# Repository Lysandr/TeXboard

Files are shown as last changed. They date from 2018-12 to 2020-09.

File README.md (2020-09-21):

# TeXboard
I designed a mechanical keyboard from scratch for the scientists, mathematicians, and control theorists of the world. It has LaTeX bindings for math and greek.

This also works as generic keyboard matrix interpretation code. Writtenin C-arduino for the teensy 3.1/2

12/1/2018 havent quite worked out some bugs in Latex, and functions. Excuse: I have spent maybe 2 hours on software.
2/14/2018 adding support for MkII.

Todo:
FN/GRK/LTX functions still need to be implemented (imlazy)
dual keys tend to have an odd glitch, needs to be investigated
MkIII hardware --> switch over to STM32 with QMK firmware... also put extension keys on the left, gives more mouse room. Create parametric case design, which prints perfectly and makes lasercut piece easier to deal with.

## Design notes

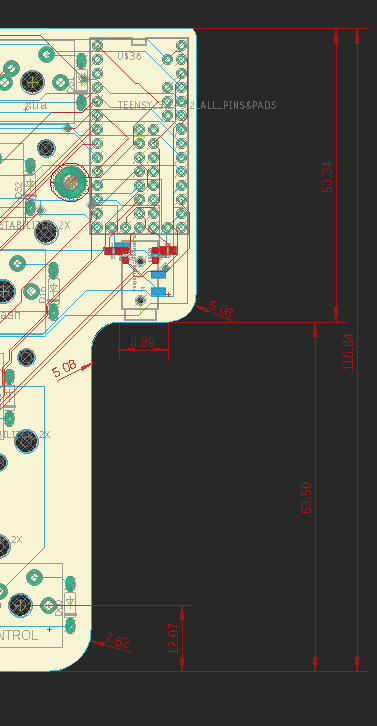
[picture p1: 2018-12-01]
dims_texbrd.PNG

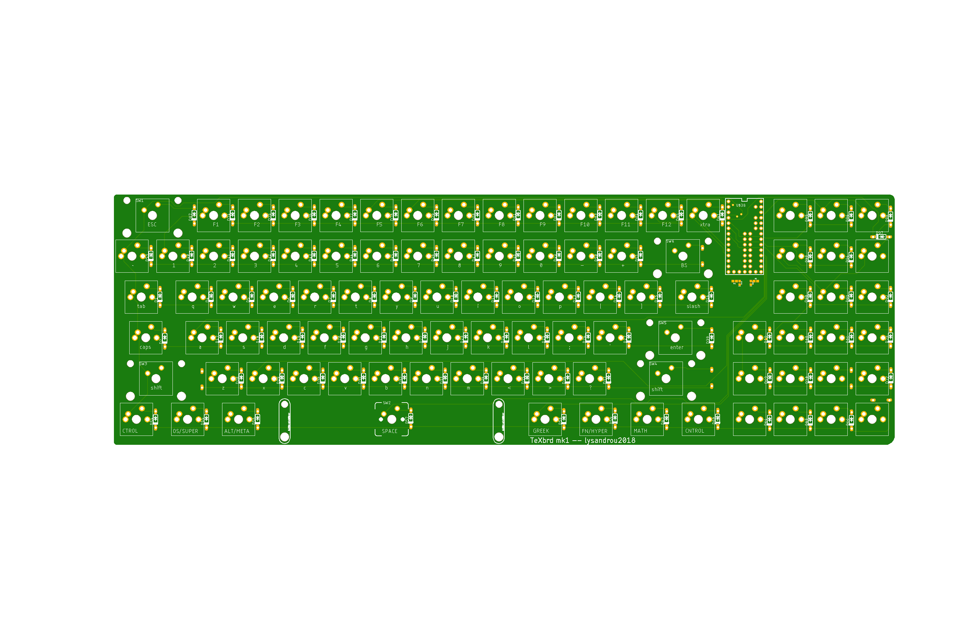
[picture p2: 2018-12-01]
texboard_hw_mk3/texboard.png

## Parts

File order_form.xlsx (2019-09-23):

Item | Quantity | Price Per
Diodes | 98 | 7
Switches: Kailh Red | 98
PCB | 1 | 5
Case | 1 | 5

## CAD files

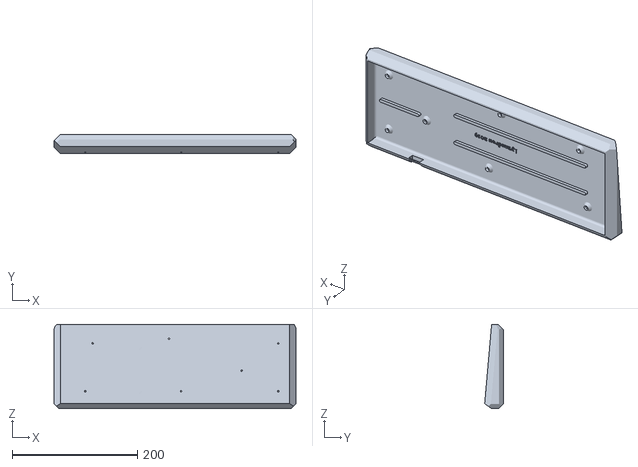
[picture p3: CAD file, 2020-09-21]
texboard.stl
385.7 x 29.7 x 134.2

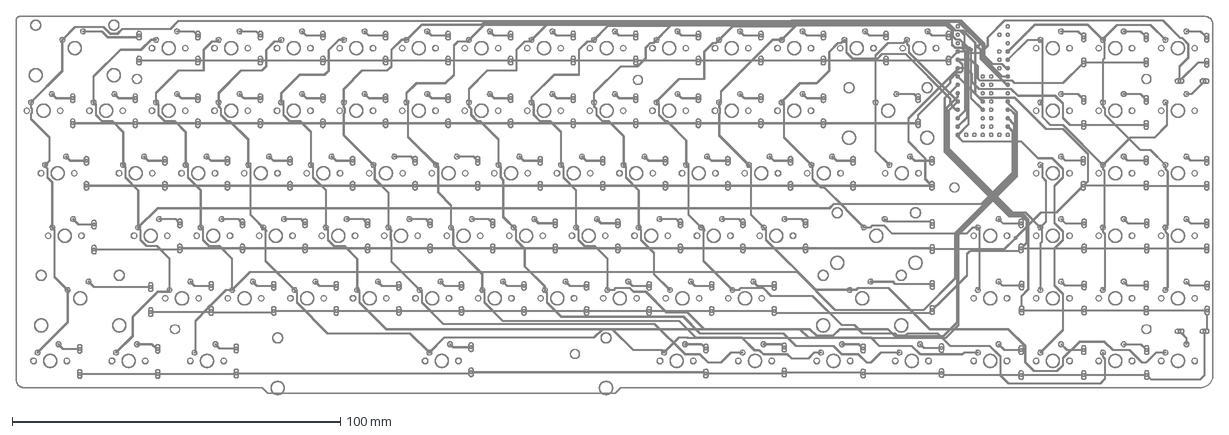
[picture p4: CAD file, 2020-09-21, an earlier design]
texboard_hw_mk2/texboard.dxf
364.5 x 115.1 mm

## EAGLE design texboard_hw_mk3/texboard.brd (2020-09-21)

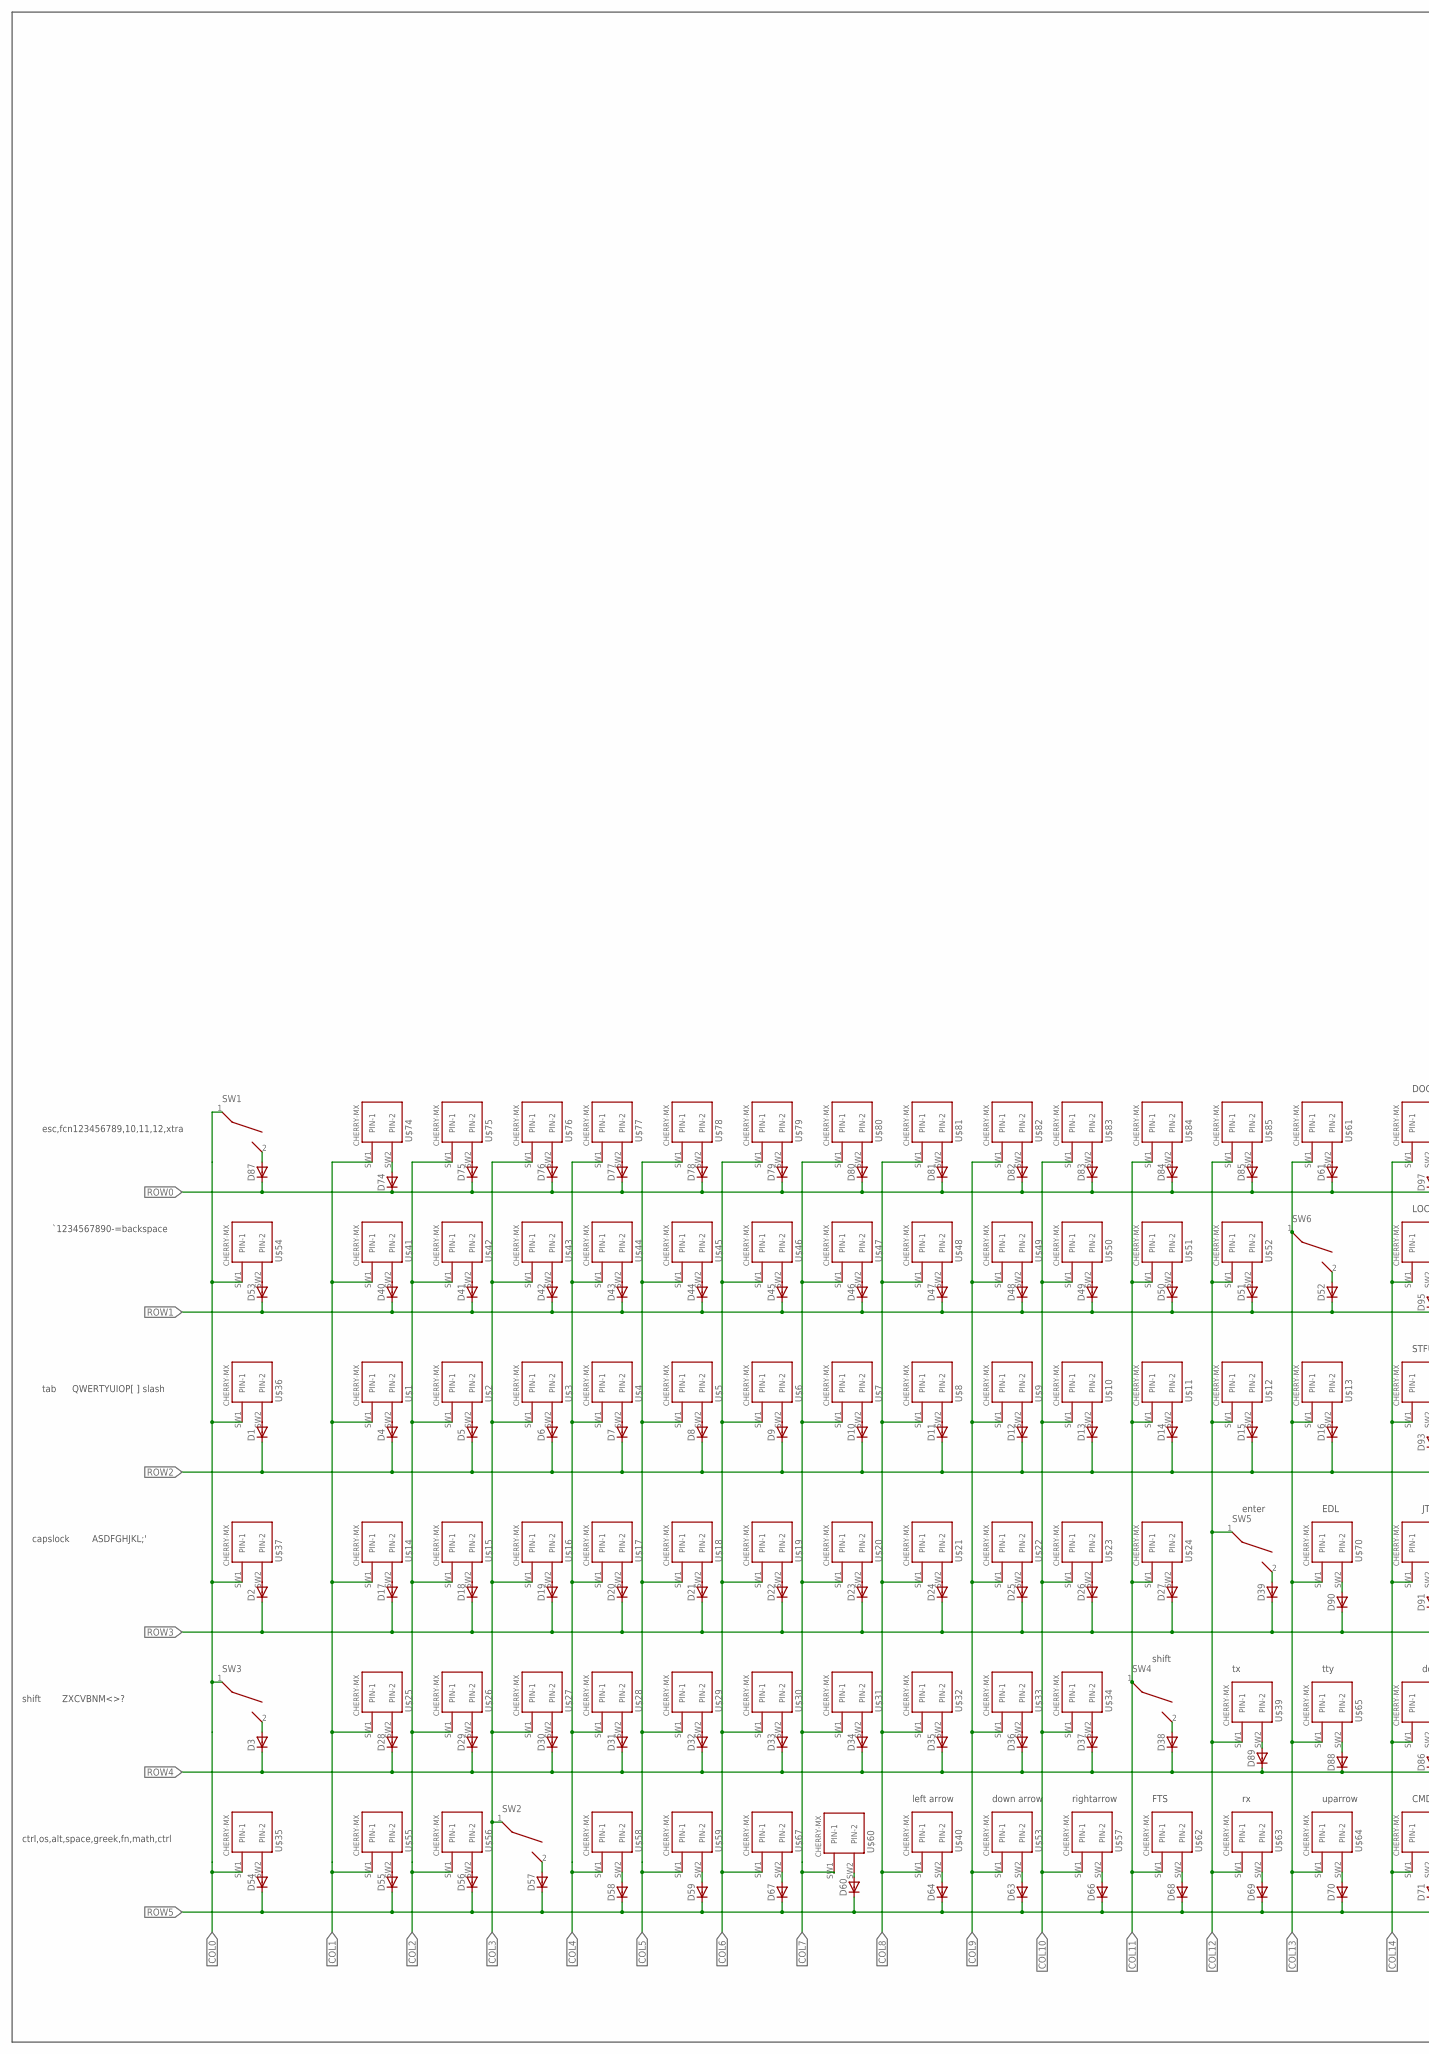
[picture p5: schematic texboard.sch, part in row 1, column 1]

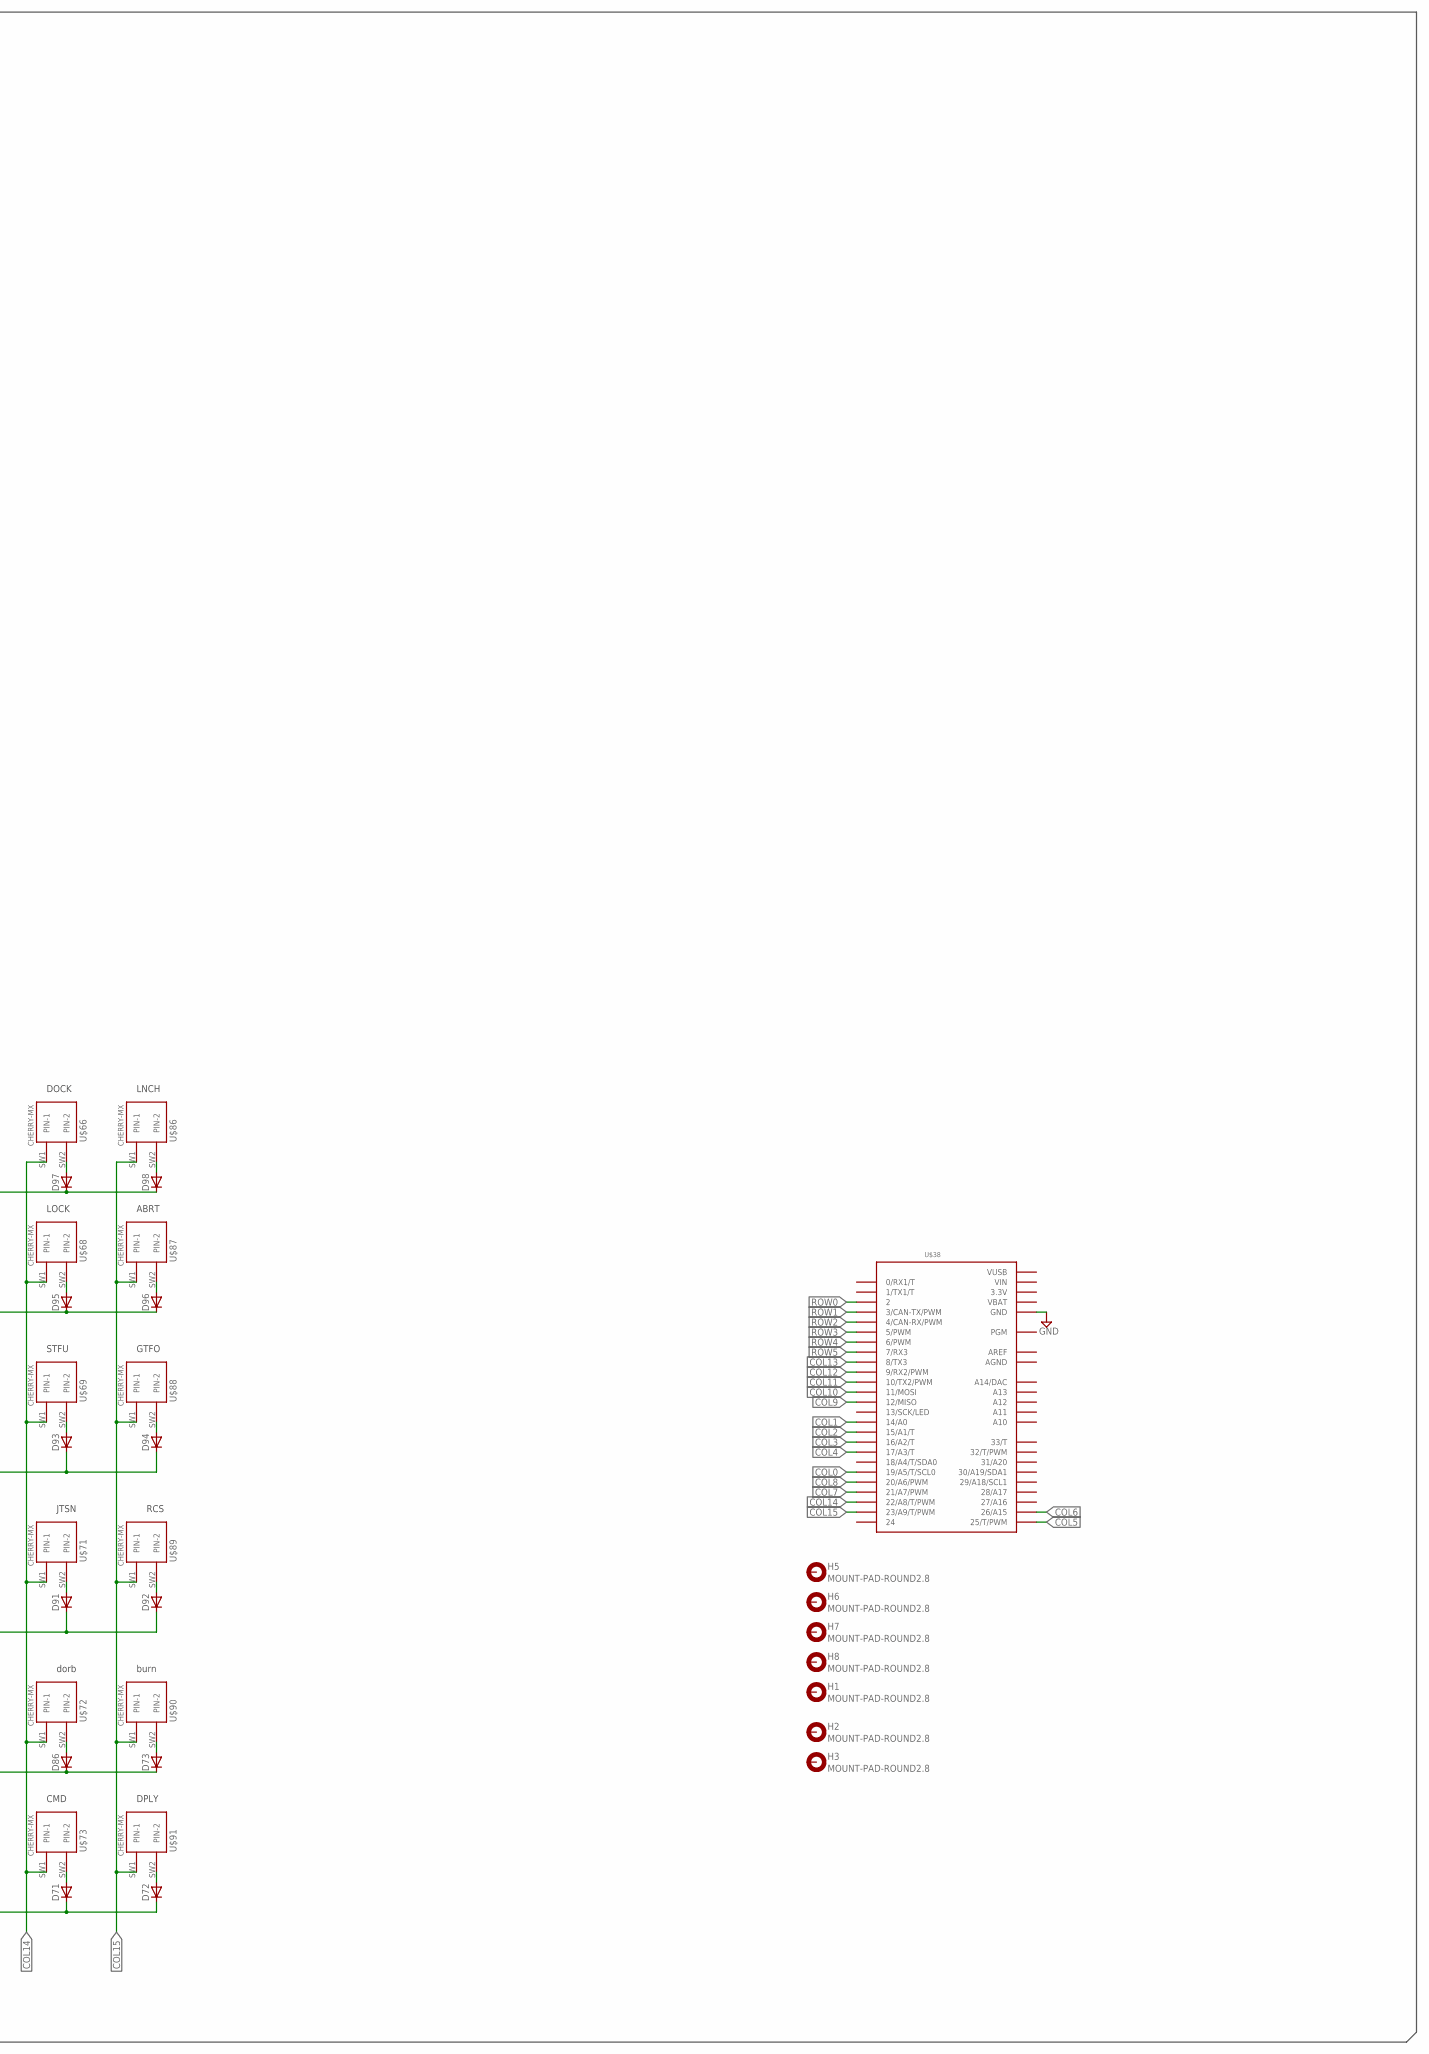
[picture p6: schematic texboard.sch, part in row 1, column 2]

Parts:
D1, D2, D3, D4, D5, D6, D7, D8, D9, D10, D11, D12, D13, D14, D15, D16, D17, D18, D19, D20, D21, D22, D23, D24, D25, D26, D27, D28, D29, D30, D31, D32, D33, D34, D35, D36, D37, D38, D39, D40, D41, D42, D43, D44, D45, D46, D47, D48, D49, D50, D51, D52, D53, D54, D55, D56, D57, D58, D59, D60, D61, D63, D64, D66, D67, D68, D69, D70, D71, D72, D73, D74, D75, D76, D77, D78, D79, D80, D81, D82, D83, D84, D85, D86, D87, D88, D89, D90, D91, D92, D93, D94, D95, D96, D97, D98: DIODE_E-DO35-7; DIODE_DO35-7
H1, H2, H3, H5, H6, H7, H8: MOUNT-PAD-ROUND2.8; 2,8-PAD
SW1, SW3, SW4, SW5, SW6: CHERRY_MX_STABILIZER_2X; MX1A-XXNN_WITH_STABILIZER_2X
SW2: CHERRY_MX_WITH_FIXING_PINS_&_STABILIZER_6.25X; MX1A-XXNW_WITH_STABILIZER_6.25X
U$1, U$2, U$3, U$4, U$5, U$6, U$7, U$8, U$9, U$10, U$11, U$12, U$13, U$14, U$15, U$16, U$17, U$18, U$19, U$20, U$21, U$22, U$23, U$24, U$25, U$26, U$27, U$28, U$29, U$30, U$31, U$32, U$33, U$34, U$35, U$36, U$37, U$39, U$40, U$41, U$42, U$43, U$44, U$45, U$46, U$47, U$48, U$49, U$50, U$51, U$52, U$53, U$54, U$55, U$56, U$57, U$58, U$59, U$60, U$61, U$62, U$63, U$64, U$65, U$66, U$67, U$68, U$69, U$70, U$71, U$72, U$73, U$74, U$75, U$76, U$77, U$78, U$79, U$80, U$81, U$82, U$83, U$84, U$85, U$86, U$87, U$88, U$89, U$90, U$91: CHERRY-MX
U$38: TEENSY_3.1-3.2_ALL_PINS&PADS; TEENSY_3.0-3.2_ALL_PINS_&_PADS

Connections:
3.3V: U$38.3.3V, U$38.3.3V1 (3.3V), U$38.3.3V2 (3.3V)
AGND: U$38.AGND
AREF: U$38.AREF
COL0: SW1.1, SW3.1, U$35.SW1 (PIN-1), U$36.SW1 (PIN-1), U$37.SW1 (PIN-1), U$38.19/A5 (19/A5/T/SCL0), U$54.SW1 (PIN-1)
COL1: U$1.SW1 (PIN-1), U$14.SW1 (PIN-1), U$25.SW1 (PIN-1), U$38.14/A0, U$41.SW1 (PIN-1), U$55.SW1 (PIN-1), U$74.SW1 (PIN-1)
COL2: U$2.SW1 (PIN-1), U$15.SW1 (PIN-1), U$26.SW1 (PIN-1), U$38.15/A1 (15/A1/T), U$42.SW1 (PIN-1), U$56.SW1 (PIN-1), U$75.SW1 (PIN-1)
COL3: SW2.1, U$3.SW1 (PIN-1), U$16.SW1 (PIN-1), U$27.SW1 (PIN-1), U$38.16/A2 (16/A2/T), U$43.SW1 (PIN-1), U$76.SW1 (PIN-1)
COL4: U$4.SW1 (PIN-1), U$17.SW1 (PIN-1), U$28.SW1 (PIN-1), U$38.17/A3 (17/A3/T), U$44.SW1 (PIN-1), U$58.SW1 (PIN-1), U$77.SW1 (PIN-1)
COL5: U$5.SW1 (PIN-1), U$18.SW1 (PIN-1), U$29.SW1 (PIN-1), U$38.25 (25/T/PWM), U$45.SW1 (PIN-1), U$59.SW1 (PIN-1), U$78.SW1 (PIN-1)
COL6: U$6.SW1 (PIN-1), U$19.SW1 (PIN-1), U$30.SW1 (PIN-1), U$38.26 (26/A15), U$46.SW1 (PIN-1), U$67.SW1 (PIN-1), U$79.SW1 (PIN-1)
COL7: U$7.SW1 (PIN-1), U$20.SW1 (PIN-1), U$31.SW1 (PIN-1), U$38.21/A7 (21/A7/PWM), U$47.SW1 (PIN-1), U$60.SW1 (PIN-1), U$80.SW1 (PIN-1)
COL8: U$8.SW1 (PIN-1), U$21.SW1 (PIN-1), U$32.SW1 (PIN-1), U$38.20/A6 (20/A6/PWM), U$40.SW1 (PIN-1), U$48.SW1 (PIN-1), U$81.SW1 (PIN-1)
COL9: U$9.SW1 (PIN-1), U$22.SW1 (PIN-1), U$33.SW1 (PIN-1), U$38.12 (12/MISO), U$49.SW1 (PIN-1), U$53.SW1 (PIN-1), U$82.SW1 (PIN-1)
COL10: U$10.SW1 (PIN-1), U$23.SW1 (PIN-1), U$34.SW1 (PIN-1), U$38.11 (11/MOSI), U$50.SW1 (PIN-1), U$57.SW1 (PIN-1), U$83.SW1 (PIN-1)
COL11: SW4.1, U$11.SW1 (PIN-1), U$24.SW1 (PIN-1), U$38.10 (10/TX2/PWM), U$51.SW1 (PIN-1), U$62.SW1 (PIN-1), U$84.SW1 (PIN-1)
COL12: SW5.1, U$12.SW1 (PIN-1), U$38.9 (9/RX2/PWM), U$39.SW1 (PIN-1), U$52.SW1 (PIN-1), U$63.SW1 (PIN-1), U$85.SW1 (PIN-1)
COL13: SW6.1, U$13.SW1 (PIN-1), U$38.8 (8/TX3), U$61.SW1 (PIN-1), U$64.SW1 (PIN-1), U$65.SW1 (PIN-1), U$70.SW1 (PIN-1)
COL14: U$38.22/A8 (22/A8/T/PWM), U$66.SW1 (PIN-1), U$68.SW1 (PIN-1), U$69.SW1 (PIN-1), U$71.SW1 (PIN-1), U$72.SW1 (PIN-1), U$73.SW1 (PIN-1)
COL15: U$38.23/A9 (23/A9/T/PWM), U$86.SW1 (PIN-1), U$87.SW1 (PIN-1), U$88.SW1 (PIN-1), U$89.SW1 (PIN-1), U$90.SW1 (PIN-1), U$91.SW1 (PIN-1)
GND: U$38.GND, U$38.GND1 (GND), U$38.GND2 (GND)
unnamed: D4.A (C), U$1.SW2 (PIN-2)
unnamed: D5.A (C), U$2.SW2 (PIN-2)
unnamed: D6.A (C), U$3.SW2 (PIN-2)
unnamed: D7.A (C), U$4.SW2 (PIN-2)
unnamed: D8.A (C), U$5.SW2 (PIN-2)
unnamed: D9.A (C), U$6.SW2 (PIN-2)
unnamed: D10.A (C), U$7.SW2 (PIN-2)
unnamed: D11.A (C), U$8.SW2 (PIN-2)
unnamed: D12.A (C), U$9.SW2 (PIN-2)
unnamed: D13.A (C), U$10.SW2 (PIN-2)
unnamed: D14.A (C), U$11.SW2 (PIN-2)
unnamed: D15.A (C), U$12.SW2 (PIN-2)
unnamed: D16.A (C), U$13.SW2 (PIN-2)
unnamed: D17.A (C), U$14.SW2 (PIN-2)
unnamed: D18.A (C), U$15.SW2 (PIN-2)
unnamed: D19.A (C), U$16.SW2 (PIN-2)
unnamed: D20.A (C), U$17.SW2 (PIN-2)
unnamed: D21.A (C), U$18.SW2 (PIN-2)
unnamed: D22.A (C), U$19.SW2 (PIN-2)
unnamed: D23.A (C), U$20.SW2 (PIN-2)
unnamed: D24.A (C), U$21.SW2 (PIN-2)
unnamed: D25.A (C), U$22.SW2 (PIN-2)
unnamed: D26.A (C), U$23.SW2 (PIN-2)
unnamed: D27.A (C), U$24.SW2 (PIN-2)
unnamed: D28.A (C), U$25.SW2 (PIN-2)
unnamed: D29.A (C), U$26.SW2 (PIN-2)
unnamed: D30.A (C), U$27.SW2 (PIN-2)
unnamed: D31.A (C), U$28.SW2 (PIN-2)
unnamed: D32.A (C), U$29.SW2 (PIN-2)
unnamed: D33.A (C), U$30.SW2 (PIN-2)
unnamed: D34.A (C), U$31.SW2 (PIN-2)
unnamed: D35.A (C), U$32.SW2 (PIN-2)
unnamed: D36.A (C), U$33.SW2 (PIN-2)
unnamed: D37.A (C), U$34.SW2 (PIN-2)
unnamed: D60.A (C), U$60.SW2 (PIN-2)
unnamed: D61.A (C), U$61.SW2 (PIN-2)
unnamed: D57.A (C), SW2.2
unnamed: D97.A (C), U$66.SW2 (PIN-2)
unnamed: D67.A (C), U$67.SW2 (PIN-2)
unnamed: D98.A (C), U$86.SW2 (PIN-2)
unnamed: D87.A (C), SW1.2
unnamed: D69.A (C), U$63.SW2 (PIN-2)
unnamed: D68.A (C), U$62.SW2 (PIN-2)
unnamed: D66.A (C), U$57.SW2 (PIN-2)
unnamed: D63.A (C), U$53.SW2 (PIN-2)
unnamed: D64.A (C), U$40.SW2 (PIN-2)
unnamed: D1.A (C), U$36.SW2 (PIN-2)
unnamed: D2.A (C), U$37.SW2 (PIN-2)
unnamed: D3.A (C), SW3.2
unnamed: D38.A (C), SW4.2
unnamed: D39.A (C), SW5.2
unnamed: D40.A (C), U$41.SW2 (PIN-2)
unnamed: D41.A (C), U$42.SW2 (PIN-2)
unnamed: D42.A (C), U$43.SW2 (PIN-2)
unnamed: D43.A (C), U$44.SW2 (PIN-2)
unnamed: D44.A (C), U$45.SW2 (PIN-2)
unnamed: D45.A (C), U$46.SW2 (PIN-2)
unnamed: D46.A (C), U$47.SW2 (PIN-2)
unnamed: D47.A (C), U$48.SW2 (PIN-2)
unnamed: D48.A (C), U$49.SW2 (PIN-2)
unnamed: D49.A (C), U$50.SW2 (PIN-2)
unnamed: D50.A (C), U$51.SW2 (PIN-2)
unnamed: D51.A (C), U$52.SW2 (PIN-2)
unnamed: D52.A (C), SW6.2
unnamed: D54.A (C), U$35.SW2 (PIN-2)
unnamed: D55.A (C), U$55.SW2 (PIN-2)
unnamed: D56.A (C), U$56.SW2 (PIN-2)
unnamed: D70.A (C), U$64.SW2 (PIN-2)
unnamed: D58.A (C), U$58.SW2 (PIN-2)
unnamed: D59.A (C), U$59.SW2 (PIN-2)
unnamed: D71.A (C), U$73.SW2 (PIN-2)
unnamed: D72.A (C), U$91.SW2 (PIN-2)
unnamed: D89.A (C), U$39.SW2 (PIN-2)
unnamed: D88.A (C), U$65.SW2 (PIN-2)
unnamed: D86.A (C), U$72.SW2 (PIN-2)
unnamed: D73.A (C), U$90.SW2 (PIN-2)
unnamed: D91.A (C), U$71.SW2 (PIN-2)
unnamed: D53.A (C), U$54.SW2 (PIN-2)
unnamed: D92.A (C), U$89.SW2 (PIN-2)
unnamed: D90.A (C), U$70.SW2 (PIN-2)
unnamed: D94.A (C), U$88.SW2 (PIN-2)
unnamed: D93.A (C), U$69.SW2 (PIN-2)
unnamed: D95.A (C), U$68.SW2 (PIN-2)
unnamed: D96.A (C), U$87.SW2 (PIN-2)
unnamed: D74.A (C), U$74.SW2 (PIN-2)
unnamed: D75.A (C), U$75.SW2 (PIN-2)
unnamed: D76.A (C), U$76.SW2 (PIN-2)
unnamed: D77.A (C), U$77.SW2 (PIN-2)
unnamed: D78.A (C), U$78.SW2 (PIN-2)
unnamed: D79.A (C), U$79.SW2 (PIN-2)
unnamed: D80.A (C), U$80.SW2 (PIN-2)
unnamed: D81.A (C), U$81.SW2 (PIN-2)
unnamed: D82.A (C), U$82.SW2 (PIN-2)
unnamed: D83.A (C), U$83.SW2 (PIN-2)
unnamed: D84.A (C), U$84.SW2 (PIN-2)
unnamed: D85.A (C), U$85.SW2 (PIN-2)
ROW0: D61.C (A), D74.C (A), D75.C (A), D76.C (A), D77.C (A), D78.C (A), D79.C (A), D80.C (A), D81.C (A), D82.C (A), D83.C (A), D84.C (A), D85.C (A), D87.C (A), D97.C (A), D98.C (A), U$38.2
ROW1: D40.C (A), D41.C (A), D42.C (A), D43.C (A), D44.C (A), D45.C (A), D46.C (A), D47.C (A), D48.C (A), D49.C (A), D50.C (A), D51.C (A), D52.C (A), D53.C (A), D95.C (A), D96.C (A), U$38.3 (3/CAN-TX/PWM)
ROW2: D1.C (A), D4.C (A), D5.C (A), D6.C (A), D7.C (A), D8.C (A), D9.C (A), D10.C (A), D11.C (A), D12.C (A), D13.C (A), D14.C (A), D15.C (A), D16.C (A), D93.C (A), D94.C (A), U$38.4 (4/CAN-RX/PWM)
ROW3: D2.C (A), D17.C (A), D18.C (A), D19.C (A), D20.C (A), D21.C (A), D22.C (A), D23.C (A), D24.C (A), D25.C (A), D26.C (A), D27.C (A), D39.C (A), D90.C (A), D91.C (A), D92.C (A), U$38.5 (5/PWM)
ROW4: D3.C (A), D28.C (A), D29.C (A), D30.C (A), D31.C (A), D32.C (A), D33.C (A), D34.C (A), D35.C (A), D36.C (A), D37.C (A), D38.C (A), D73.C (A), D86.C (A), D88.C (A), D89.C (A), U$38.6 (6/PWM)
ROW5: D54.C (A), D55.C (A), D56.C (A), D57.C (A), D58.C (A), D59.C (A), D60.C (A), D63.C (A), D64.C (A), D66.C (A), D67.C (A), D68.C (A), D69.C (A), D70.C (A), D71.C (A), D72.C (A), U$38.7 (7/RX3)
VBAT: U$38.VBAT
VIN: U$38.VIN
VUSB: U$38.VUSB

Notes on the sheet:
QWERTYUIOP[ ] slash
ASDFGHJKL;'
ZXCVBNM<>?
shift
capslock
tab
enter
`1234567890-=backspace
ctrl,os,alt,space,greek,fn,math,ctrl
esc,fcn123456789,10,11,12,xtra
left arrow
down arrow
rightarrow
FTS
DPLY
CMD
uparrow
tty
dorb
burn
EDL
JTSN
RCS
STFU
GTFO
LOCK
ABRT
DOCK
LNCH

Board: 2 copper layers, 200 parts (6 on the bottom side), 120 nets, no tracks yet.

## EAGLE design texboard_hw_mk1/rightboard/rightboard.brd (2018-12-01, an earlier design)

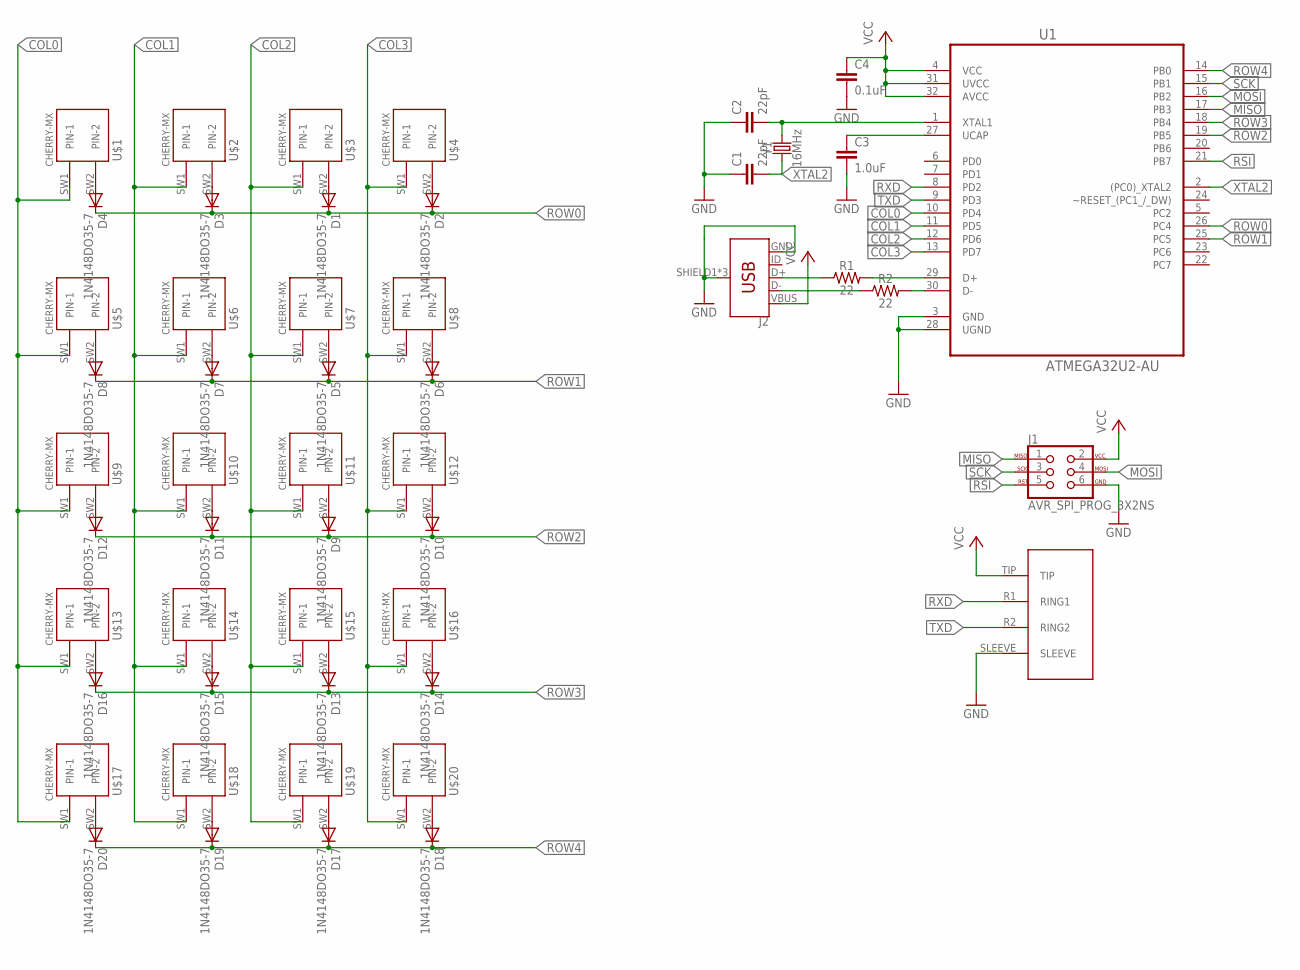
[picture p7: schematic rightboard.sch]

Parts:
C1, C2: 22pF; 0603
C3: 1.0uF; 0603
C4: 0.1uF; 0603
D1, D2, D3, D4, D5, D6, D7, D8, D9, D10, D11, D12, D13, D14, D15, D16, D17, D18, D19, D20: 1N4148DO35-7; DO35-7
J1: AVR_SPI_PROG_3X2NS; 2X3-NS
J2: USB_MICRO-B_FEMALE-SMT; USB-B-MICRO-SMD
R1, R2: 22; 0603
U1: ATMEGA32U2-AU; QFP80P900X900X120-32N
U$1, U$2, U$3, U$4, U$5, U$6, U$7, U$8, U$9, U$10, U$11, U$12, U$13, U$14, U$15, U$16, U$17, U$18, U$19, U$20: CHERRY-MX
U$21: 54-00035
Y1: 16MHz; HC49US

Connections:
COL0: U1.10 (PD4), U$1.SW1 (PIN-1), U$5.SW1 (PIN-1), U$9.SW1 (PIN-1), U$13.SW1 (PIN-1), U$17.SW1 (PIN-1)
COL1: U1.11 (PD5), U$2.SW1 (PIN-1), U$6.SW1 (PIN-1), U$10.SW1 (PIN-1), U$14.SW1 (PIN-1), U$18.SW1 (PIN-1)
COL2: U1.12 (PD6), U$3.SW1 (PIN-1), U$7.SW1 (PIN-1), U$11.SW1 (PIN-1), U$15.SW1 (PIN-1), U$19.SW1 (PIN-1)
COL3: U1.13 (PD7), U$4.SW1 (PIN-1), U$8.SW1 (PIN-1), U$12.SW1 (PIN-1), U$16.SW1 (PIN-1), U$20.SW1 (PIN-1)
GND: C1.1, C2.1, C3.2, C4.2, J1.6, J2.GND, J2.SHIELD1 (SHIELD), J2.SHIELD2 (SHIELD), J2.SHIELD3 (SHIELD), U1.3 (GND), U1.28 (UGND), U$21.SLEEVE
MISO: J1.1, U1.17 (PB3)
MOSI: J1.4, U1.16 (PB2)
unnamed: D1.A, U$3.SW2 (PIN-2)
unnamed: D2.A, U$4.SW2 (PIN-2)
unnamed: D3.A, U$2.SW2 (PIN-2)
unnamed: D4.A, U$1.SW2 (PIN-2)
unnamed: D5.A, U$7.SW2 (PIN-2)
unnamed: D6.A, U$8.SW2 (PIN-2)
unnamed: D7.A, U$6.SW2 (PIN-2)
unnamed: D8.A, U$5.SW2 (PIN-2)
unnamed: D9.A, U$11.SW2 (PIN-2)
unnamed: D10.A, U$12.SW2 (PIN-2)
unnamed: D11.A, U$10.SW2 (PIN-2)
unnamed: D12.A, U$9.SW2 (PIN-2)
unnamed: D13.A, U$15.SW2 (PIN-2)
unnamed: D14.A, U$16.SW2 (PIN-2)
unnamed: D15.A, U$14.SW2 (PIN-2)
unnamed: D16.A, U$13.SW2 (PIN-2)
unnamed: D17.A, U$19.SW2 (PIN-2)
unnamed: D18.A, U$20.SW2 (PIN-2)
unnamed: D19.A, U$18.SW2 (PIN-2)
unnamed: D20.A, U$17.SW2 (PIN-2)
unnamed: C2.2, U1.1 (XTAL1), Y1.2
unnamed: R1.2, U1.29 (D+)
unnamed: J2.D+, R1.1
unnamed: J2.D-, R2.1
unnamed: R2.2, U1.30 (D-)
unnamed: C3.1, U1.27 (UCAP)
ROW0: D1.C, D2.C, D3.C, D4.C, U1.26 (PC4)
ROW1: D5.C, D6.C, D7.C, D8.C, U1.25 (PC5)
ROW2: D9.C, D10.C, D11.C, D12.C, U1.19 (PB5)
ROW3: D13.C, D14.C, D15.C, D16.C, U1.18 (PB4)
ROW4: D17.C, D18.C, D19.C, D20.C, U1.14 (PB0)
RSI: J1.5, U1.21 (PB7)
RXD: U1.8 (PD2), U$21.R1 (RING1)
SCK: J1.3, U1.15 (PB1)
TXD: U1.9 (PD3), U$21.R2 (RING2)
VCC: C4.1, J1.2, J2.VBUS, U1.4 (VCC), U1.31 (UVCC), U1.32 (AVCC), U$21.TIP
XTAL2: C1.2, U1.2 ((PC0)_XTAL2), Y1.1

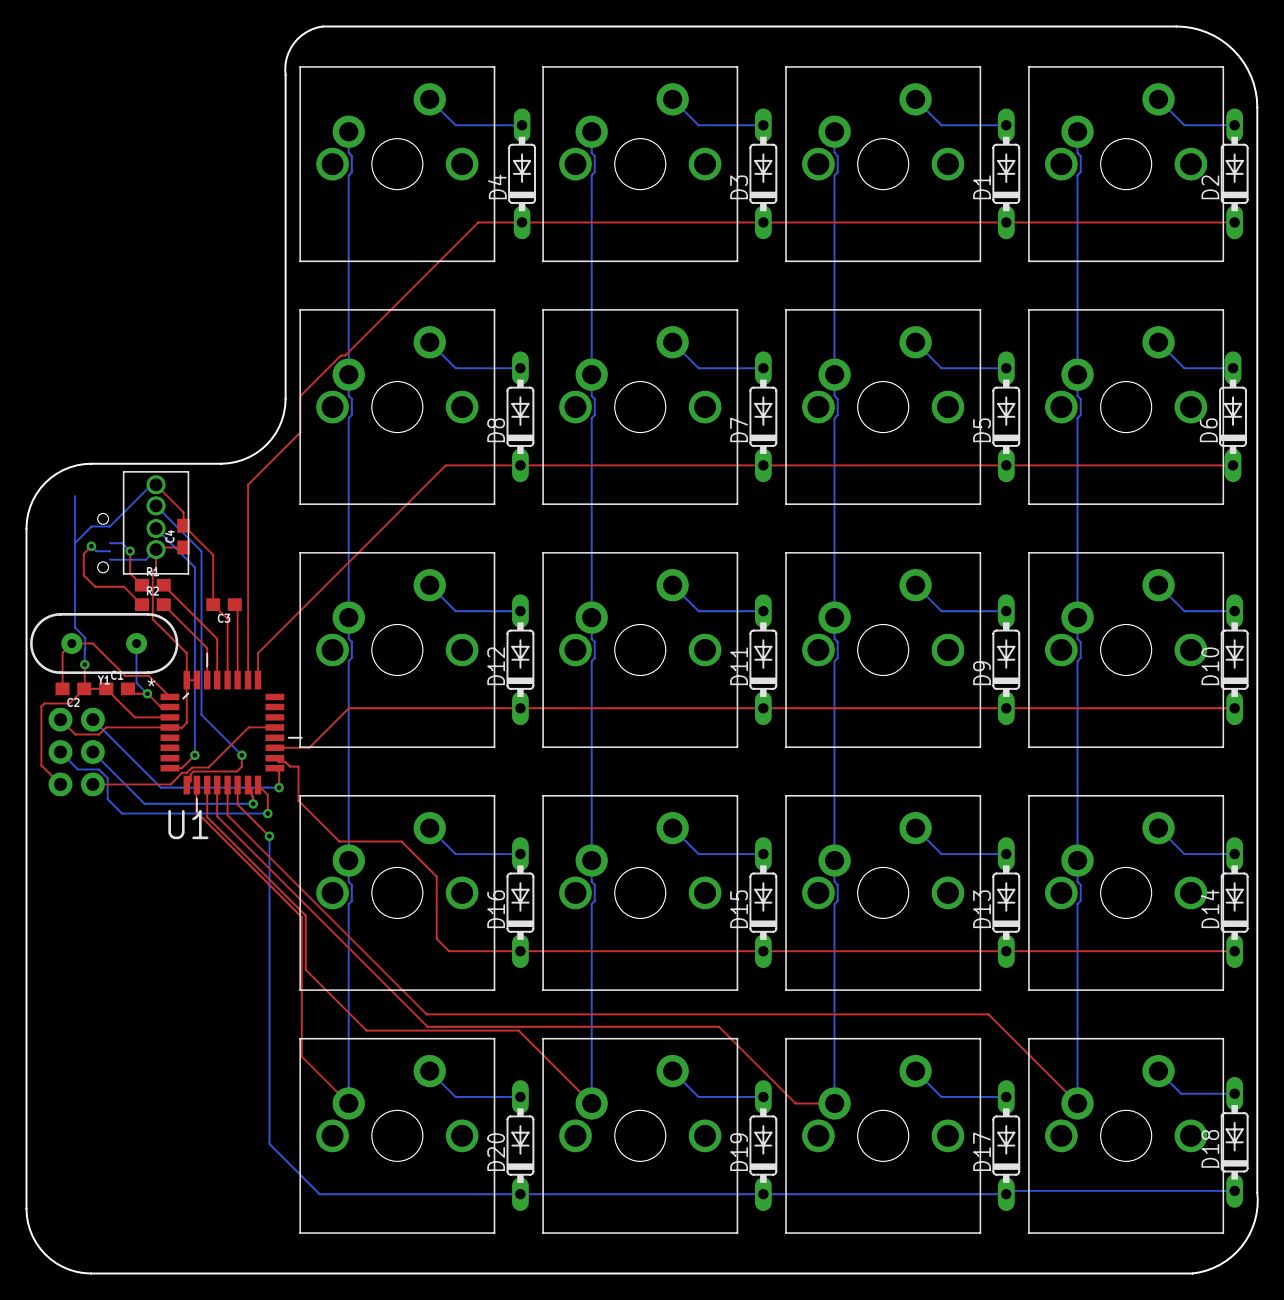
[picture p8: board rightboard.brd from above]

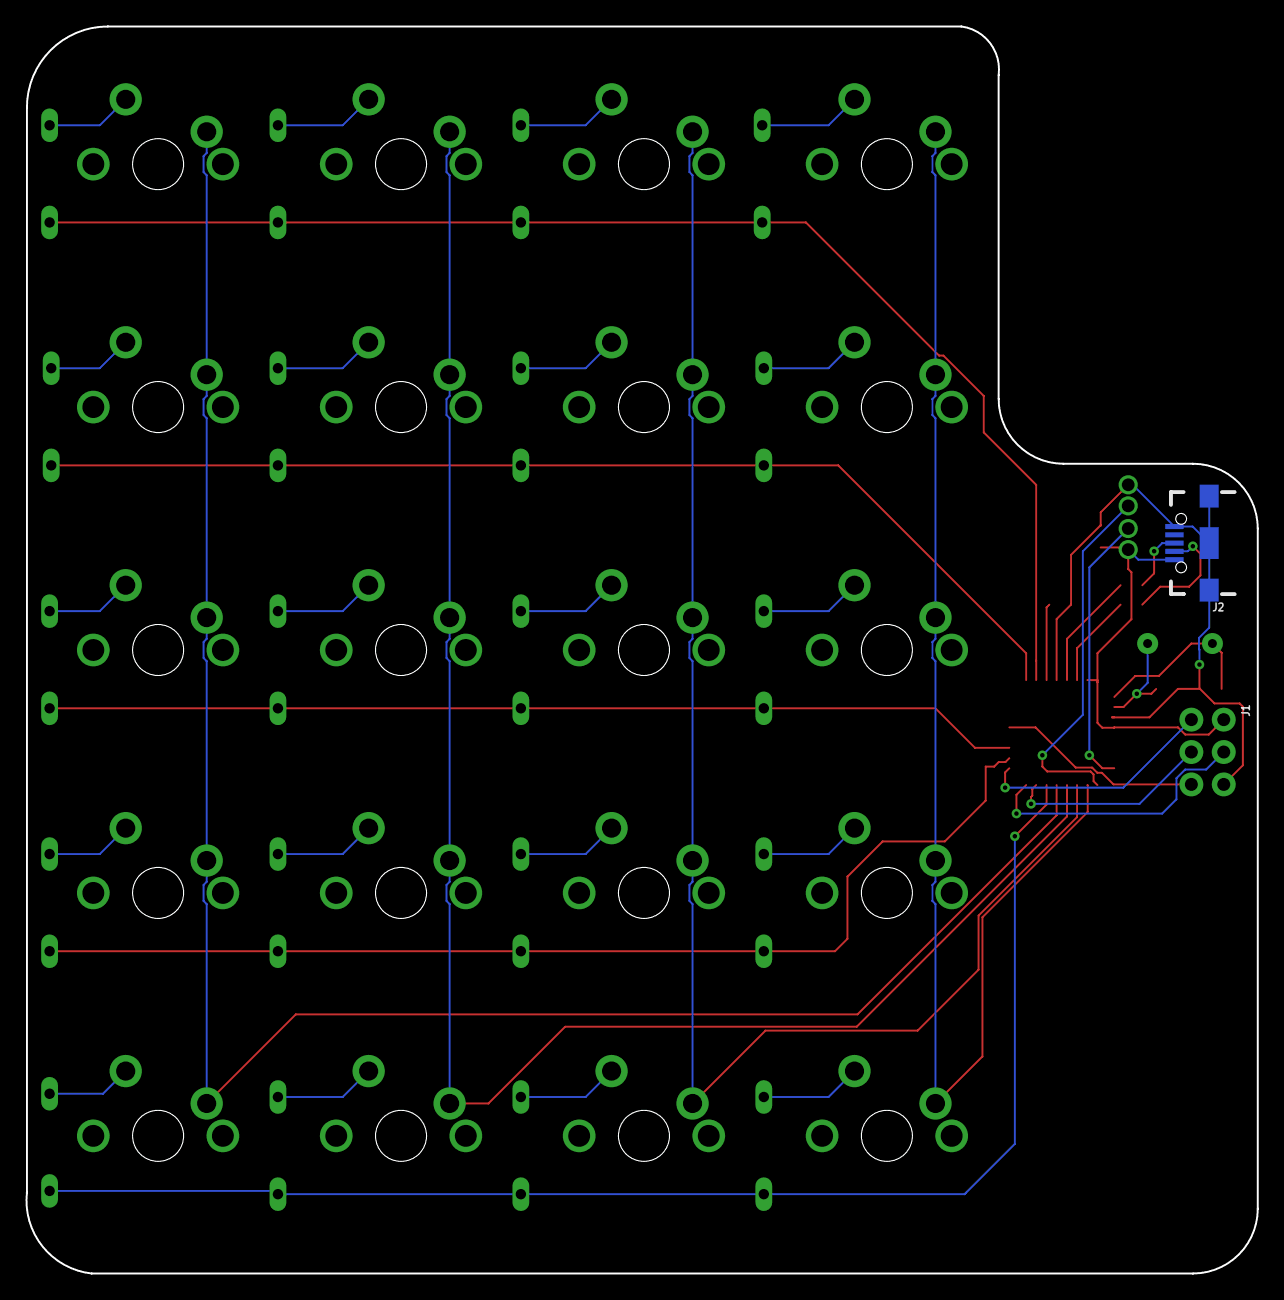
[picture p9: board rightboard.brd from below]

Board: 2 copper layers, 96.6 x 97.8 mm, 51 parts (2 on the bottom side), 44 nets.

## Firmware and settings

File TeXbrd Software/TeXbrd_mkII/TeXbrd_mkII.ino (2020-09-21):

/* Teensy USB keyboard
 *  Padraig Lysandrou September 2018
 * Open issues:
 * Function keys need to work
*/
#include <Keyboard.h>

#define GREEK 0xfe
#define MATH 0xff
#define KEY_NONE 0x00
#define KEY_FXN 0xfd
#define KEY_XTRA KEY_DELETE 

const byte COLS = 16;   //fourteen columns
const byte ROWS = 6;    //six rows
byte colPins[COLS] = {19,14,15,16,17,25,26,21,20,12,11,10,9,8,22,23};
byte rowPins[ROWS] = {2,3,4,5,6,7};
unsigned int keys_pressed[6] = {0};
unsigned int modifiers_pressed[2] = {0};
int cycle_time_ms = 5;
int FXN_flag = 0;


unsigned long last_debounce_time[ROWS][COLS] = {0};  // the last time the output pin was toggled
unsigned long time_since_last_TX[ROWS][COLS] = {0};
int last_button_state[ROWS][COLS] = {0};
unsigned long debounceDelay = 15;    // the debounce time; increase if the output flickers
unsigned long transmitDelay = 15;

unsigned int key_matrix[ROWS][COLS] = {
  {KEY_ESC,KEY_F1,KEY_F2,KEY_F3,KEY_F4,KEY_F5,KEY_F6,KEY_F7,KEY_F8,KEY_F9,KEY_F10,KEY_F11,KEY_F12,KEY_XTRA,KEY_NONE,KEY_NONE},
  {KEY_TILDE,KEY_1,KEY_2,KEY_3,KEY_4,KEY_5,KEY_6,KEY_7,KEY_8,KEY_9,KEY_0,KEY_MINUS,KEY_EQUAL,KEY_BACKSPACE,KEY_NONE,KEY_NONE},
  {KEY_TAB,KEY_Q,KEY_W,KEY_E,KEY_R,KEY_T,KEY_Y,KEY_U,KEY_I,KEY_O,KEY_P,KEY_LEFT_BRACE,KEY_RIGHT_BRACE,KEY_BACKSLASH,KEY_NONE,KEY_NONE},
  {KEY_CAPS_LOCK,KEY_A,KEY_S,KEY_D,KEY_F,KEY_G,KEY_H,KEY_J,KEY_K,KEY_L,KEY_SEMICOLON,KEY_QUOTE,KEY_ENTER,KEY_NONE,KEY_NONE,KEY_NONE},
  {MODIFIERKEY_SHIFT,KEY_Z,KEY_X,KEY_C,KEY_V,KEY_B,KEY_N,KEY_M,KEY_COMMA,KEY_PERIOD,KEY_SLASH,MODIFIERKEY_RIGHT_SHIFT,KEY_NONE,KEY_NONE,KEY_NONE,KEY_NONE},
  {MODIFIERKEY_CTRL,MODIFIERKEY_GUI,MODIFIERKEY_ALT,KEY_SPACE,GREEK,KEY_FXN,MATH,MODIFIERKEY_RIGHT_CTRL,KEY_LEFT_ARROW,KEY_DOWN_ARROW,KEY_RIGHT_ARROW,KEY_NONE,KEY_NONE,KEY_UP_ARROW,KEY_NONE,KEY_NONE}
};


/* this sets up all of our row/col pins 
 * and initializes keyboard
 */
void setup() {
  pinMode(13,OUTPUT);
  for(int row = 0; row < ROWS; row++){
    pinMode(rowPins[row], INPUT_PULLDOWN);
  }
  for(int col = 0; col < COLS; col++){
    pinMode(colPins[col], OUTPUT);
    digitalWrite(colPins[col], LOW);
  }
  Keyboard.begin();
  Serial.begin(9600);
}


// testing the keyboard now
bool there_exists(unsigned int key){
  for(int i=0; i<6; i++){
    if(keys_pressed[i] == key){
      return(true);
    }
  }
  return(false);
}


void fn_handler(int key_to_lookat){
  remove_key(key_to_lookat);
  switch(key_to_lookat){
    case KEY_F11:
      // Keyboard.print("KEY_F11");
      Keyboard.press(   KEY_MEDIA_VOLUME_INC);
      Keyboard.releaseAll();
      break;
    case KEY_F10:
      // Keyboard.print("KEY_F10");
      Keyboard.press(   KEY_MEDIA_VOLUME_DEC);
      Keyboard.releaseAll();
      break;
    case KEY_F9:
      // Keyboard.print("KEY_F9");
      Keyboard.press(   KEY_MEDIA_PLAY_PAUSE);
      Keyboard.releaseAll();
      break;
    case KEY_F8:
      // Keyboard.print("KEY_F8");
      Keyboard.press(   KEY_MEDIA_NEXT_TRACK);
      Keyboard.releaseAll();
      break;
    case KEY_F7:
      // Keyboard.print("KEY_F7");
      Keyboard.press(   KEY_MEDIA_PREV_TRACK);
      Keyboard.releaseAll();
      break;
    case KEY_ESC:
      // Keyboard.print("ESC");
      Keyboard.press(   KEY_MEDIA_MUTE);
      Keyboard.releaseAll();
      break;
    }
}
void math_handler(){}
void greek_handler(){}

/* Just to check if the key is a modifier
 */
bool check_for_modifier(unsigned int key_to_lookat){
  switch(key_to_lookat){
    case MODIFIERKEY_SHIFT:       return(true);
    case MODIFIERKEY_RIGHT_SHIFT: return(true);
    case MODIFIERKEY_CTRL:        return(true);
    case MODIFIERKEY_GUI:         return(true);
    case MODIFIERKEY_ALT:         return(true);
    case MODIFIERKEY_RIGHT_CTRL:  return(true);
  }
  return(false);
}

void remove_key(unsigned int key){
  if(key != 0){
    for(int i=0; i<6; i++){
      if(keys_pressed[i] == key){
        keys_pressed[i] = 0;
        digitalWrite(13,LOW);
        //Serial.println("key released");
        }
    }
  }
}

void add_key(unsigned int key){
  for(int i=0; i<6; i++){
    if(keys_pressed[i] == 0){
      keys_pressed[i] = key;
      digitalWrite(13,HIGH);
      //Serial.println("key clicked");
      break;
      }
  }
}

// if the mod is not already in the array, find a place that is zero and put it there.
void add_mod_list(unsigned int key){
  // if it is not already in there, find a place to put it
  if(modifiers_pressed[0] != key && modifiers_pressed[1] != key){
    if(modifiers_pressed[0] == 0x00){modifiers_pressed[0] = key;}
    else if(modifiers_pressed[1] == 0x00){modifiers_pressed[1] = key;}
  }
}

// remove the modifier (out of both if we have to!)
void remove_mod_list(unsigned int key){
  if(modifiers_pressed[0] == key){
    modifiers_pressed[0] = 0x00;
  }
  if(modifiers_pressed[1] == key){
    modifiers_pressed[1] = 0x00;
  }
}

void debounce_key_matrix(int row, int col){
  int state = digitalRead(rowPins[row]);
  int key_to_lookat = key_matrix[row][col];
  
  // If the state of the key has changed, log this time...
  if (state != last_button_state[row][col]) {
    last_debounce_time[row][col] = millis();
    if(key_to_lookat == KEY_FXN){
      FXN_flag = state;
    }
  }
  
  // Basically figure out what to do after the debounce time delay
  if ((millis() - last_debounce_time[row][col]) > debounceDelay) {
    // Check for new modifier being pressed
    if (state == 1 && check_for_modifier(key_to_lookat)){
      add_mod_list(key_to_lookat);
      Keyboard.set_modifier(modifiers_pressed[0] | modifiers_pressed[1]);
      Keyboard.send_now();
    }
    // remove any stale modifiers
    else if (state !=1 && check_for_modifier(key_to_lookat)){
      remove_mod_list(key_to_lookat);
      Keyboard.set_modifier(modifiers_pressed[0] | modifiers_pressed[1]);
      Keyboard.send_now();
    }
    // If a key state is high, and passed the transmit delay, add that key to the queue
    else if((key_to_lookat!=KEY_FXN) && state==1 && (millis()-time_since_last_TX[row][col]) > transmitDelay ){
      //Serial.println("key has been hit");
      add_key(key_to_lookat);
      if(FXN_flag && ((millis()-time_since_last_TX[row][col]) > 3*transmitDelay)){
        fn_handler(key_to_lookat);
      }
      time_since_last_TX[row][col] = millis();
    }
    // otherwise remove any stale keypresses that we dont want
    else if(state !=1 && !check_for_modifier(key_to_lookat)){
      remove_key(key_to_lookat);
    }
  }
  // Update the last known state of each key in the matrix
  last_button_state[row][col] = state;
}

void send_keys(){
  remove_key(KEY_FXN);
  remove_key(MATH);
  remove_key(GREEK);
  Keyboard.set_key1(keys_pressed[0]);
  Keyboard.set_key2(keys_pressed[1]);
  Keyboard.set_key3(keys_pressed[2]);
  Keyboard.set_key4(keys_pressed[3]);
  Keyboard.set_key5(keys_pressed[4]);
  Keyboard.set_key6(keys_pressed[5]);
  Keyboard.send_now();
}


void loop_key_matrix(){
  for(int col = 0; col < COLS; col++){
    digitalWrite(colPins[col], HIGH);
    for(int row = 0; row < ROWS; row++){
      debounce_key_matrix(row,col); 
    }
    digitalWrite(colPins[col], LOW);
  }
  send_keys();
}


void loop() {
  delay(cycle_time_ms);
  loop_key_matrix();
}

/* 
*  
*
 */

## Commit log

2018-12-01 adding hardware and software
    [rightboard.brd, rightboard.sch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]
2019-02-12 fixed some shit maybe idk
    [TeXbrd_mkII.ino]
2019-10-26 adding dxf fuckery
    [texboard.brd, texboard.dxf]
2020-09-21 whatever new shit i added
    [texboard.stl]

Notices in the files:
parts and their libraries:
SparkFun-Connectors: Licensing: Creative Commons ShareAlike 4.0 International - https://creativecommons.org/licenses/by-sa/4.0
